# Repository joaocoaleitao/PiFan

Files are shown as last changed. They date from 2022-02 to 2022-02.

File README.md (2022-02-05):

# PiFan
A simple opensource project of an hat to cool you Raspberry.

Started this project because mostly all my Raspberrys end up overheating and then throttling.
So here it is!
The PiFan!
Simply put is a stackable HAT for raspberry, it can run a 100% all the time if you remove the jumper JP3 and that way you can also use the GPIO 17 for other things. Or you can keep the jumper and run the script in Python at boot and it will use the settings to control the speed through PWM.

My first tests suggest a maximum temperature of around 50C when using the fan while testing with "cpuburn-a53".

The HAT can slide down the existing GPIO pins and be tightened with a screw or you can solder a female connector (which can be the long pin version so you can stack another hat on top.)

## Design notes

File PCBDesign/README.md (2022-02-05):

# PiFan
The files in this directory are the EagleCad project as well as the Gerber files generated for production.

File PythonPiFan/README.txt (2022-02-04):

This Python script controls the fan speed and temperature settings.
Copy the PythonPiFan folder to "/opt" folder and insert a line in crontab "@reboot cd /opt/PythonPiFan/ && python3 /opt/PythonPiFan/fan.py"
The file settings.ini in the PythonPiFan folder contains the following settings:

MinimumTemperature : Receives a number from where the temperature curve should start. 
Example: "MinimumTemperature = 25" if you want to start the fan climb at 25 Celsius degrees.

MaximumTemperature : Receives a number up to where the curve will grow. This effectively sets the 100% speed of the fan ceiling.
Example: "MaximumTemperature = 60" if you want the fan to hit 100% at 60 degrees

UpdateInterval : The interval at which the fan speed are updated based on current temperature.
Example: "UpdateInterval = 3" if you want to update the fan speed based on current temperature every 3 seconds.

MinimumFanSpeed : The minimum speed in percentage that the fan should rotate.
Example: "MinimumFanSpeed = 25" if you want the fan to never rotate a less than 25%

MaximumFanSpeed : The maximum speed in percentage that the fan should rotate.
Example: "MaximumFanSpeed = 90" to set the fan rotation speed at a maximum of 90%

Debug : If you want to print current settings and interval values.
Example: "Debug = 1" to print the values. set debug to zero if you want to turn them off

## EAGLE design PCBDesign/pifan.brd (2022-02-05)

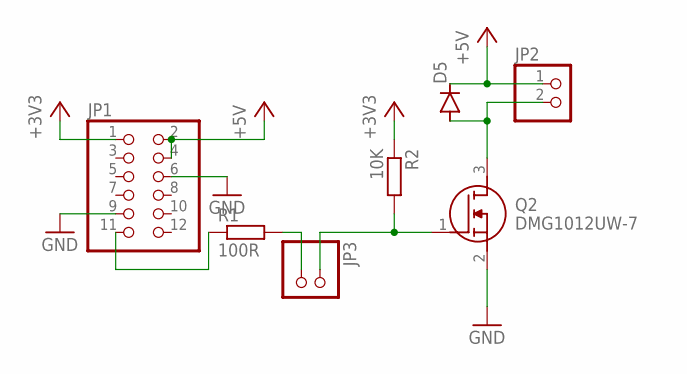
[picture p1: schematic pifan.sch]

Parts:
D5: DIODE-SOD123; SOD123
JP1: PINHD-2X6; 2X06
JP2: PINHD-1X2; 1X02
JP3: PINHD-1X21X02SQUARE; 1X02SQUARE
Q2: DMG1012UW-7; SOT65P210X100-3N
R1: 100R; R0805
R2: 10K; R0805

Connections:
+3V3: JP1.1, R2.1
+5V: D5.C, JP1.2, JP1.4, JP2.1
GND: JP1.6, JP1.9, Q2.2 (S)
unnamed: JP1.11, R1.1
unnamed: JP3.2, R1.2
unnamed: D5.A, JP2.2, Q2.3 (D)
unnamed: JP3.1, Q2.1 (G), R2.2

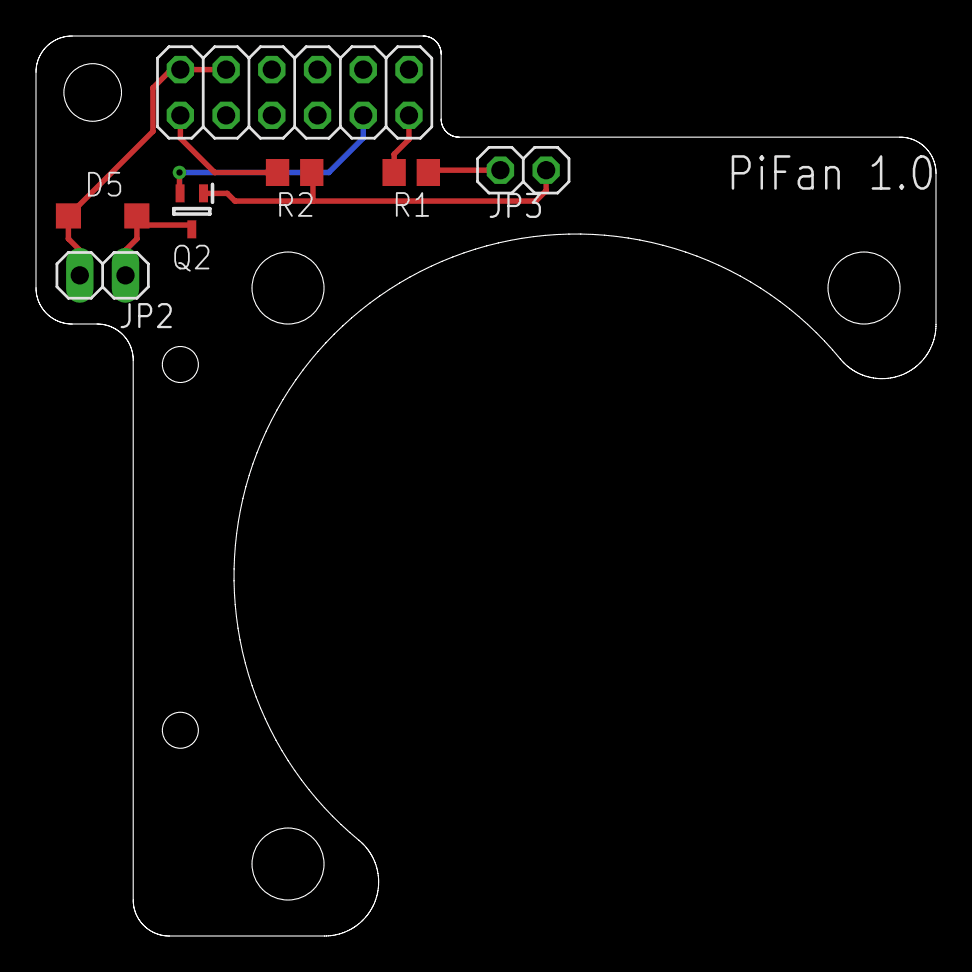
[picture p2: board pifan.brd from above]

Board: 2 copper layers, 50.0 x 50.0 mm, 7 parts (0 on the bottom side), 7 nets.

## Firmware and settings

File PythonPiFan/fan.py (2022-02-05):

import logging
import logging.handlers
from gpiozero import PWMOutputDevice, CPUTemperature
import configparser
import time

class PiFan(object):

    def __init__(self):
        self.read_settings()
        self.device = PWMOutputDevice(17,initial_value = 1)
        self.temp =CPUTemperature(min_temp = self.minimum_temperature, max_temp = self.maximum_temperature, threshold = self.minimum_temperature)
        self.debug = 1
    def fan_on(self):
        self.device.on()

    def fan_off(self):
        self.device.off()

    def fan_value(self, value):
        self.device.value = value

    def get_temperature(self):
        return self.temp.temperature

    def read_settings(self):
        cfg = configparser.ConfigParser()
        cfg.read('settings.ini')
        cfg.sections()
        self.minimum_temperature = float(cfg['MAIN']['MinimumTemperature'])
        self.maximum_temperature = float(cfg['MAIN']['MaximumTemperature'])
        self.interval = int(cfg['MAIN']['UpdateInterval'])
        self.minimum_fan = int(cfg['MAIN']['MinimumFanSpeed'])/100
        self.maximum_fan = int(cfg['MAIN']['MaximumFanSpeed'])/100
        self.debug = int(cfg['MAIN']['Debug'])
        self.log_delay = int(cfg['MAIN']['LogDelay'])

    def get_fan_value_from_temp(self):
        if self.temp.value < self.minimum_fan:
            return self.minimum_fan
        elif self.temp.value > self.maximum_fan:
            return self.maximum_fan
        return self.temp.value

if __name__ == '__main__':
    formatter = logging.Formatter('%(name)s - %(message)s')
    pifan_logger = logging.getLogger('PiFanLogger')
    pifan_logger.setLevel(logging.DEBUG)
    handler = logging.handlers.SysLogHandler(address = '/dev/log')
    handler.setFormatter(formatter)
    pifan_logger.addHandler(handler)

    pifan = PiFan()
    pifan.read_settings()
    if pifan.debug == 1:
        pifan_logger.info("Current Settings:")
        pifan_logger.info("Log Update Interval:" + str(pifan.log_delay))
        pifan_logger.info("Fan Update Interval Speed:" + str(pifan.interval))
        pifan_logger.info("Maximum Temperature:" + str(pifan.maximum_temperature))
        pifan_logger.info("Minimum Temperature:" + str(pifan.minimum_temperature))
        pifan_logger.info("Maximum Fan Speed:" + str(pifan.maximum_fan*100))
        pifan_logger.info("Minimum Fan Speed:" + str(pifan.minimum_fan*100))
    
    first_timestamp = 0
    while 1:
        time.sleep(pifan.interval)
        pifan.fan_value(pifan.get_fan_value_from_temp())
        if pifan.debug == 1:
            if time.time() > first_timestamp + pifan.log_delay:
                pifan_logger.info("Current Temperature " + str(round(pifan.temp.temperature,1)) + " | Current Speed " + str(int(pifan.get_fan_value_from_temp() *100))+ "%")
                first_timestamp = time.time()

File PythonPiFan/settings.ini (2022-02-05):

[MAIN]
MinimumTemperature = 40
MaximumTemperature = 65
UpdateInterval = 3
MinimumFanSpeed = 25
MaximumFanSpeed = 100
Debug = 1
LogDelay = 60
